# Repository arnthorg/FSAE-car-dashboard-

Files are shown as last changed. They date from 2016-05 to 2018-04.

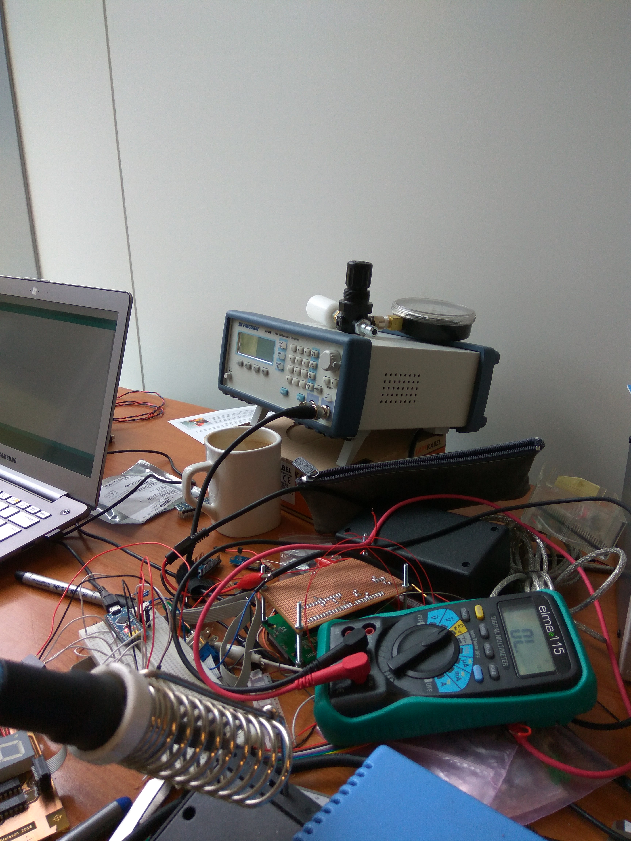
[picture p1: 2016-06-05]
myndir/IMG_20160512_113833.jpg

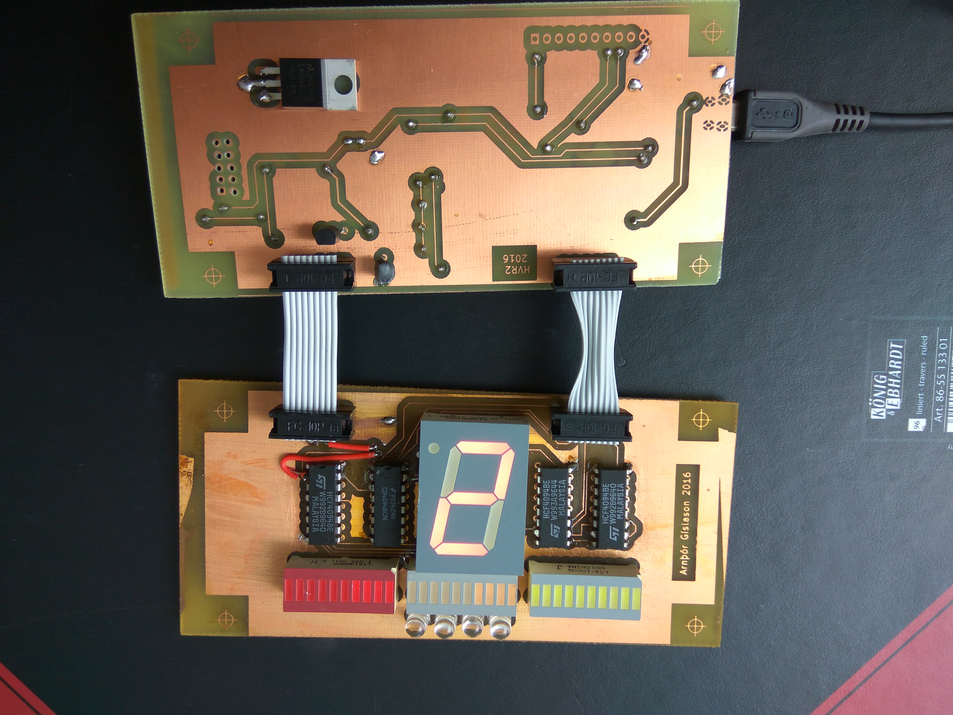
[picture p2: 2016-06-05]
myndir/IMG_20160516_171026.jpg

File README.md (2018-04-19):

# A dashboard with rpm bar-graph, gear display, shift-light and oil pressure/  AFR / Speed for RU's 2016 FSAE car 

It's programmed in the arduino environment 

It has:
* engine RPM bargraph, 
* shift light
* OLED display capable if displaying any analog value
* 7-seg gear selected display

Dash-OLED/ contains the main program

PCB/ contains the PCB design

lid/ contains the sketch for the lid that enclosed the electronics

myndir/ contains some images of the project

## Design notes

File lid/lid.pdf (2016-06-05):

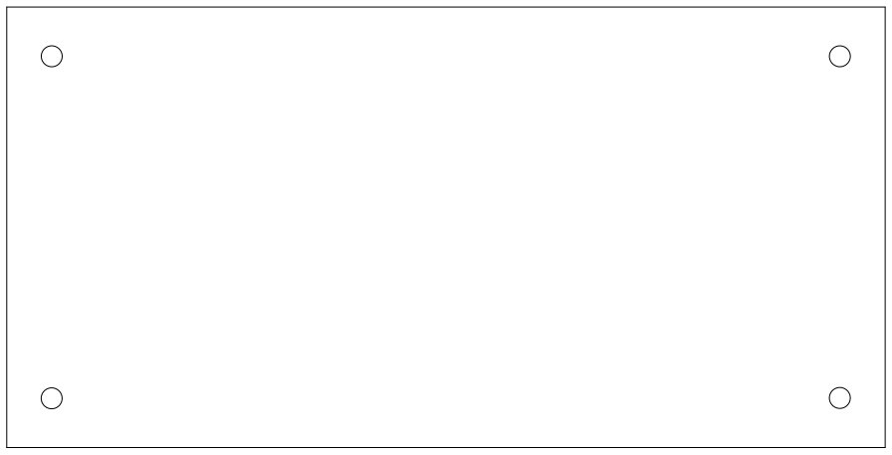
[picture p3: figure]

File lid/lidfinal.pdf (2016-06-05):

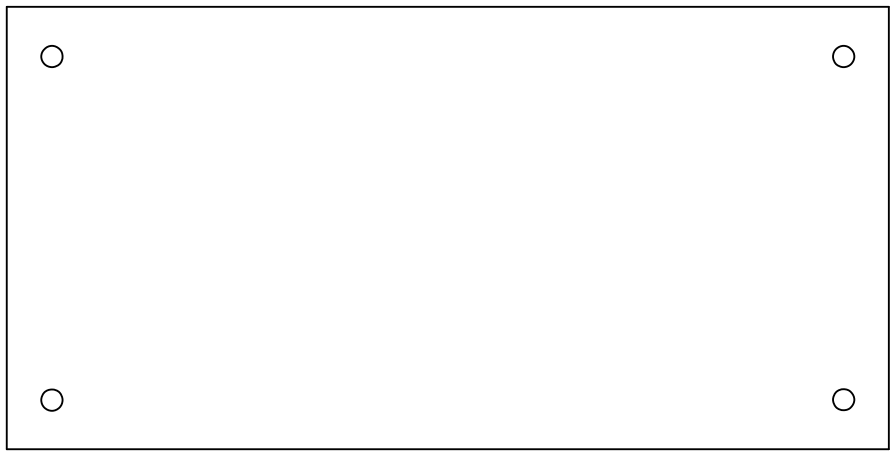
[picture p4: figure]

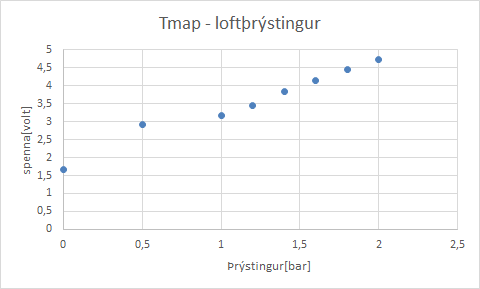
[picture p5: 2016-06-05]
myndir/airpress.png

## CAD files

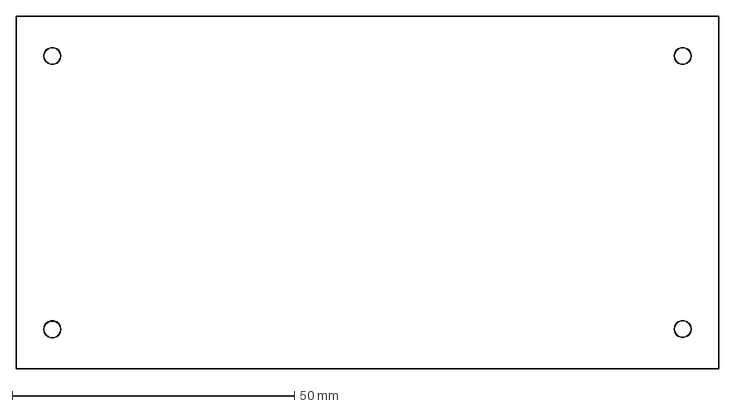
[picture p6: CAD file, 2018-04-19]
lid/lid-F.Fab.dxf
124.5 x 62.4 mm

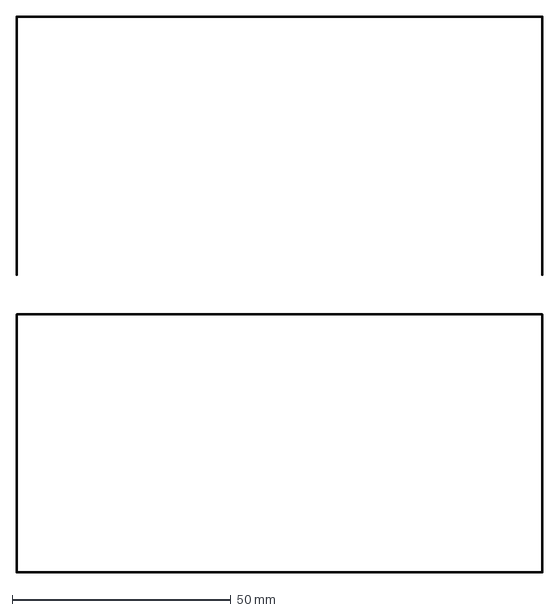
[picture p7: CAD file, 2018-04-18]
PCB/dxf/bargraph-Edge.Cuts.dxf
120.2 x 127.2 mm

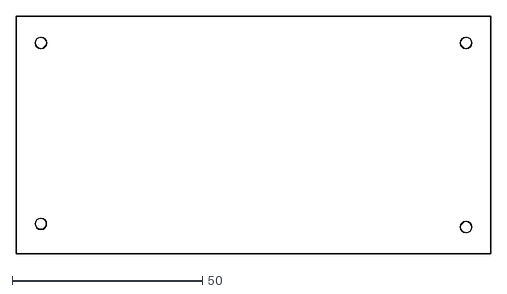
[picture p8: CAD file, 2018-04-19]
lid/Untitled.dxf
124.5 x 62.4

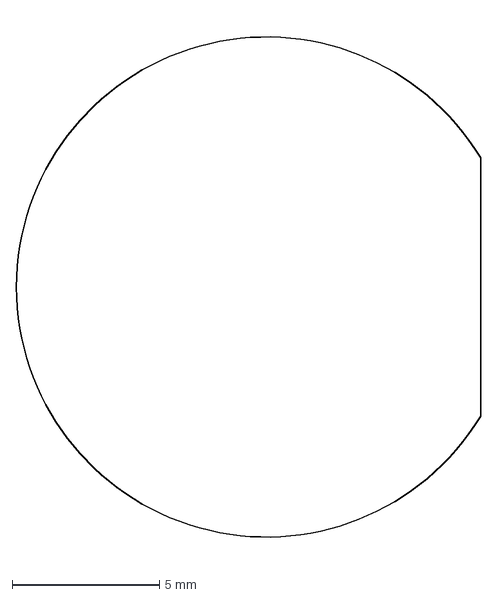
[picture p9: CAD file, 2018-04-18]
lid/conn.dxf
15.8 x 18.4 mm

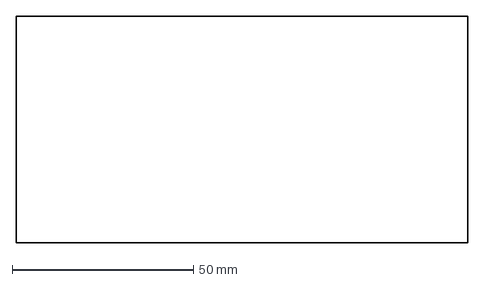
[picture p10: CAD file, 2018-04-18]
lid/#lid.dxf
124.5 x 62.4 mm

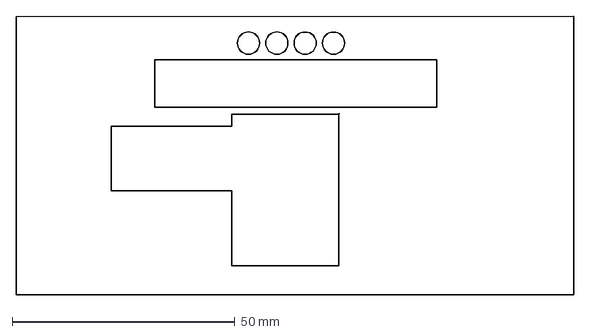
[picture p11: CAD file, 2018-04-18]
lid/spjald.dxf
125.0 x 62.5 mm

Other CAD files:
PCB/dxf/bargraph-F.SilkS.dxf
lid/lid.dxf

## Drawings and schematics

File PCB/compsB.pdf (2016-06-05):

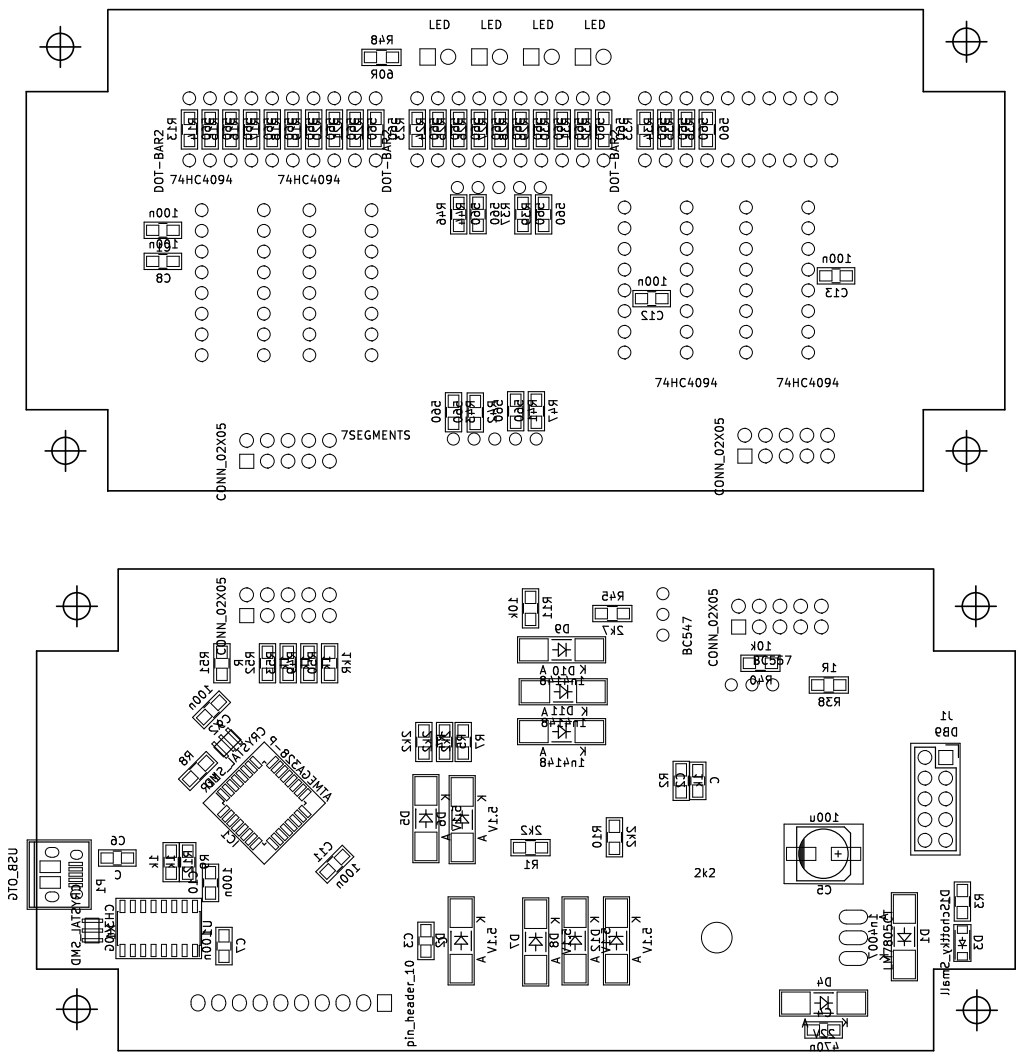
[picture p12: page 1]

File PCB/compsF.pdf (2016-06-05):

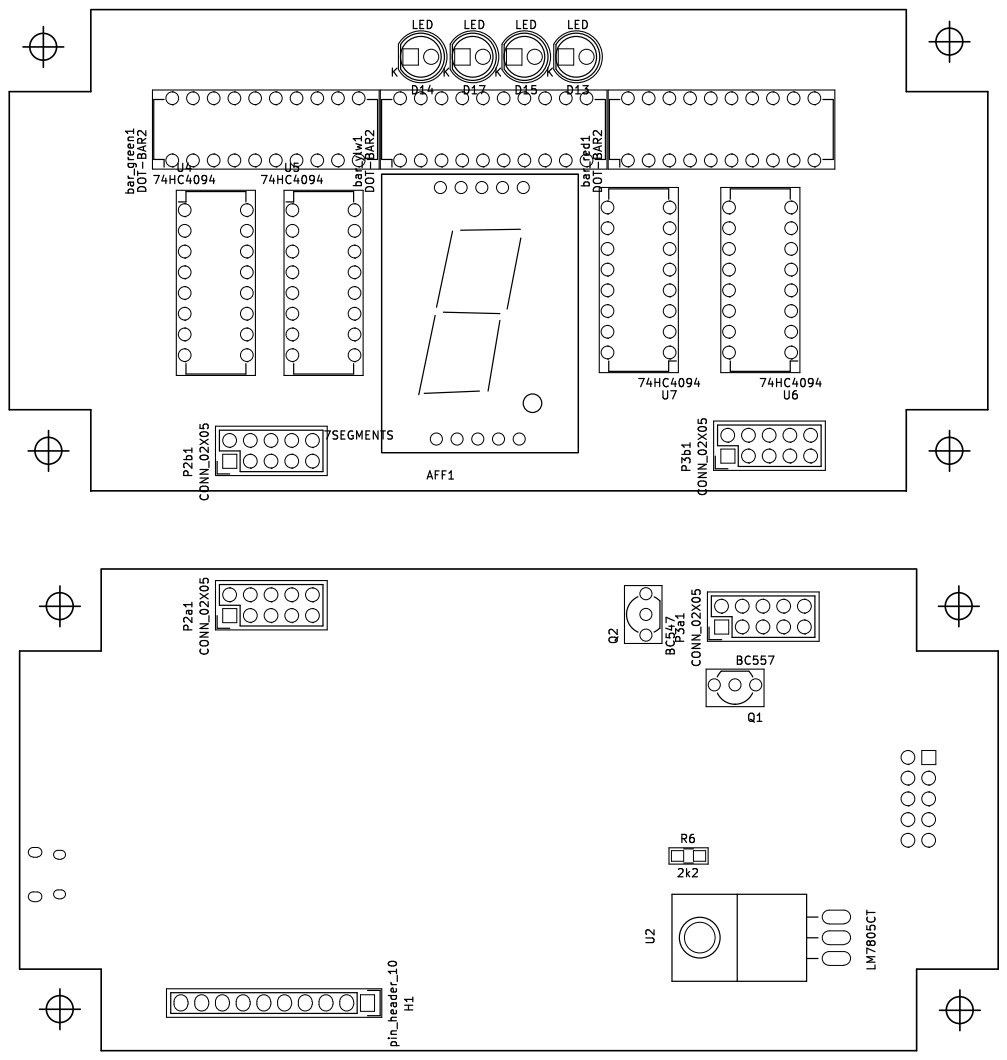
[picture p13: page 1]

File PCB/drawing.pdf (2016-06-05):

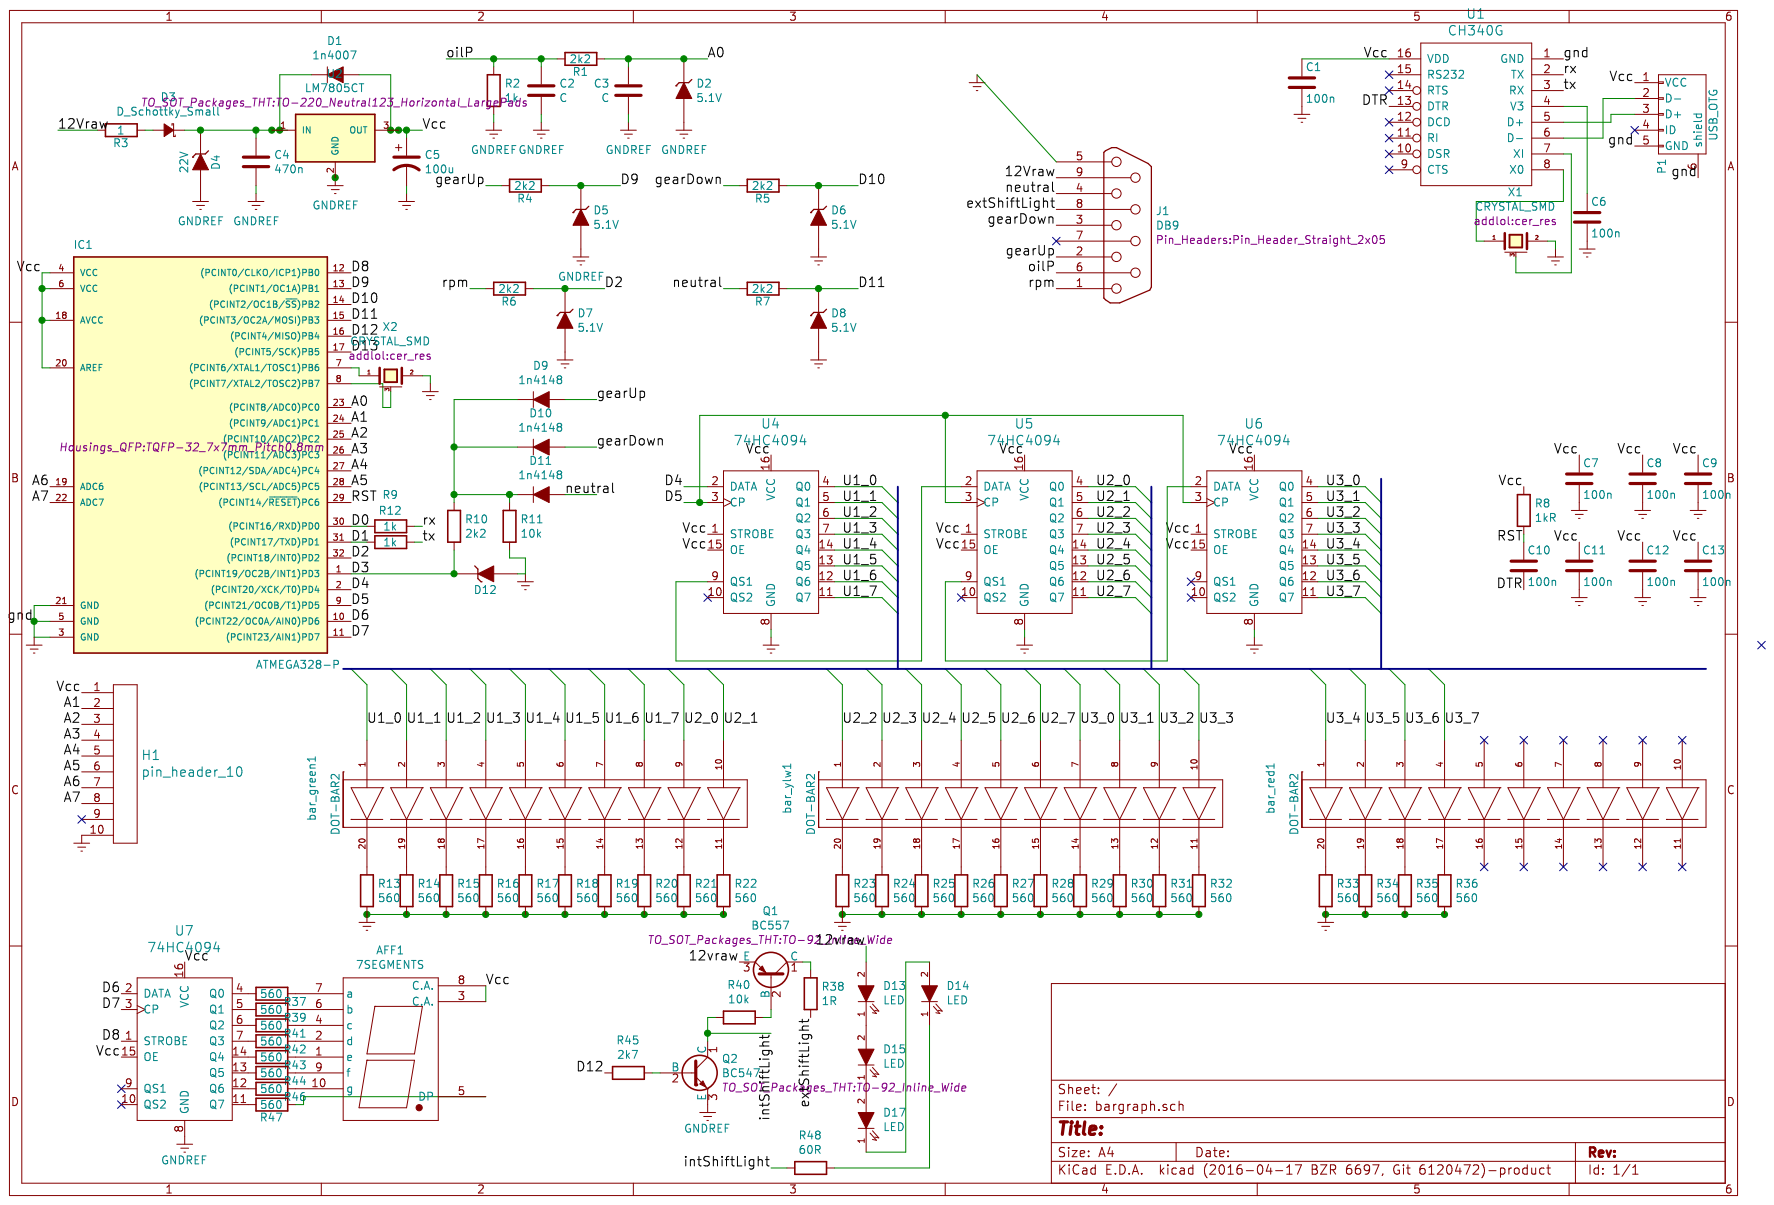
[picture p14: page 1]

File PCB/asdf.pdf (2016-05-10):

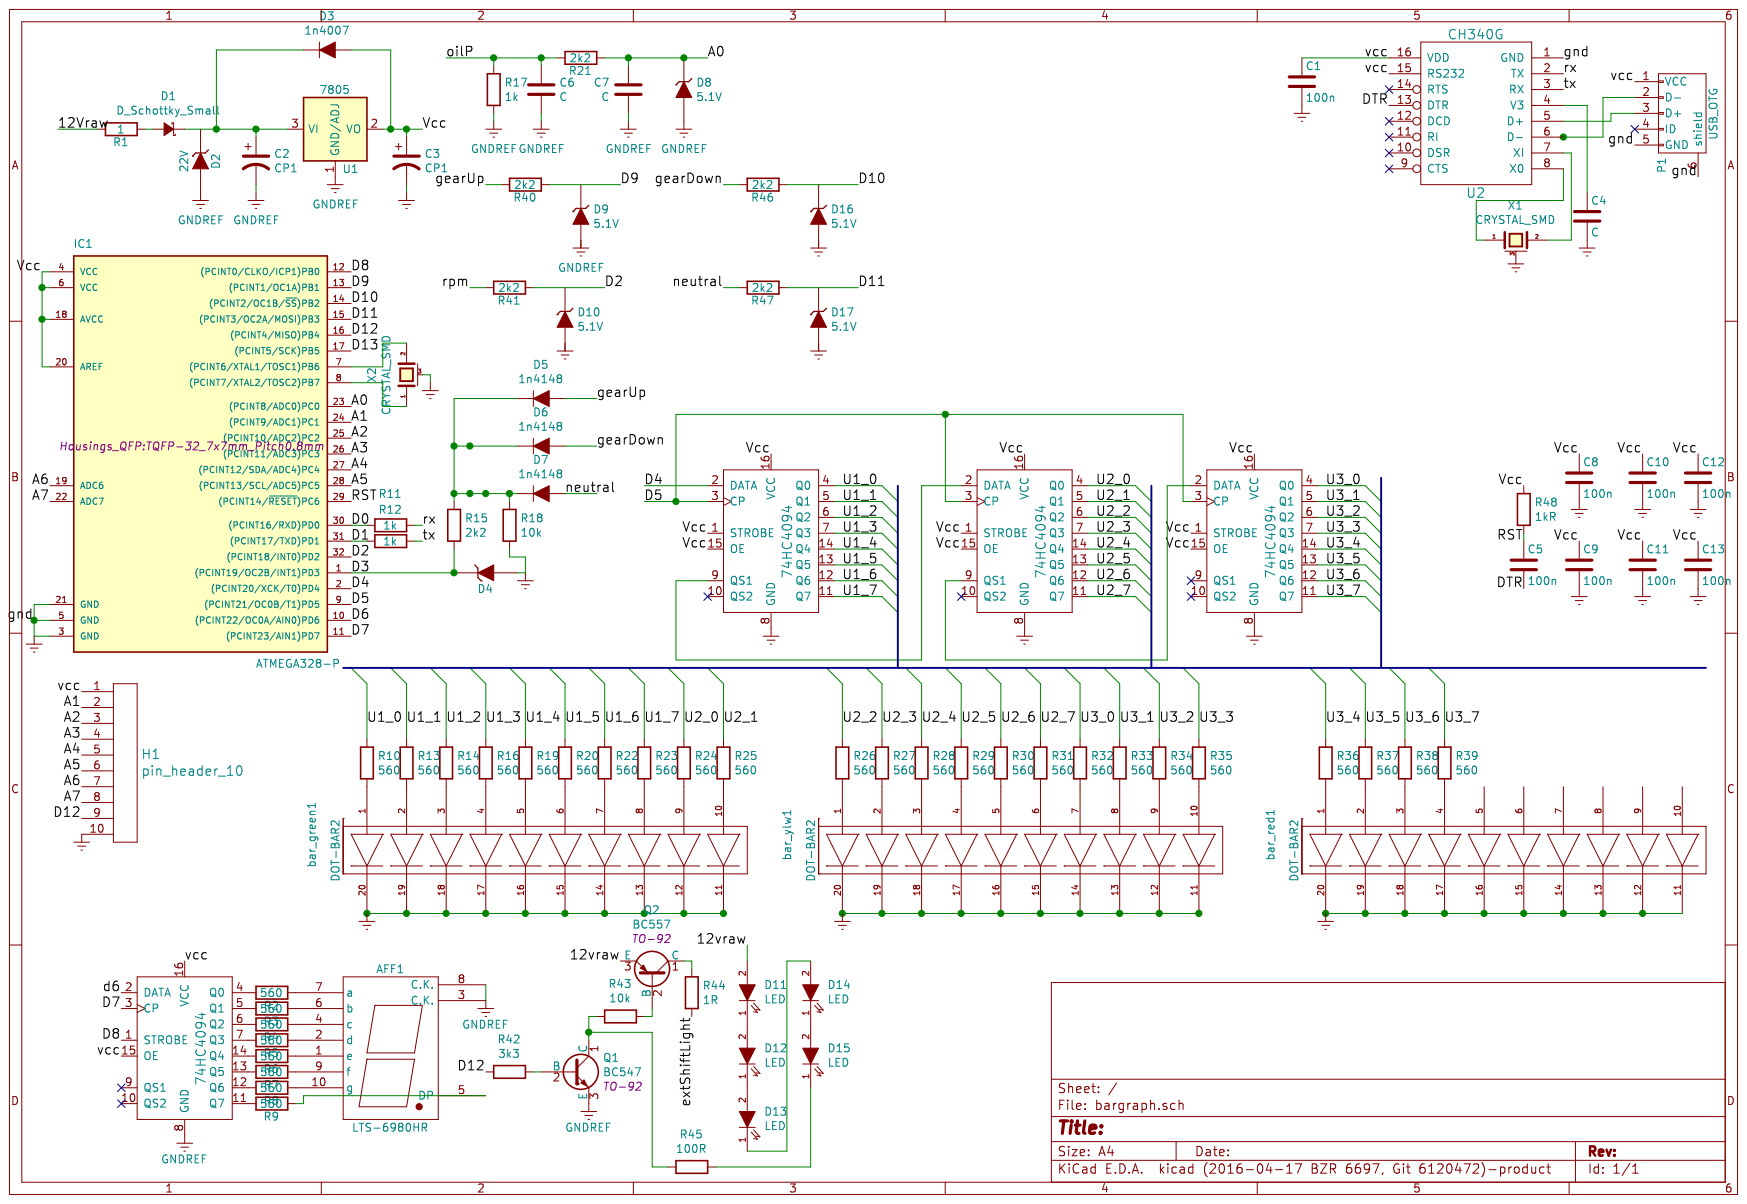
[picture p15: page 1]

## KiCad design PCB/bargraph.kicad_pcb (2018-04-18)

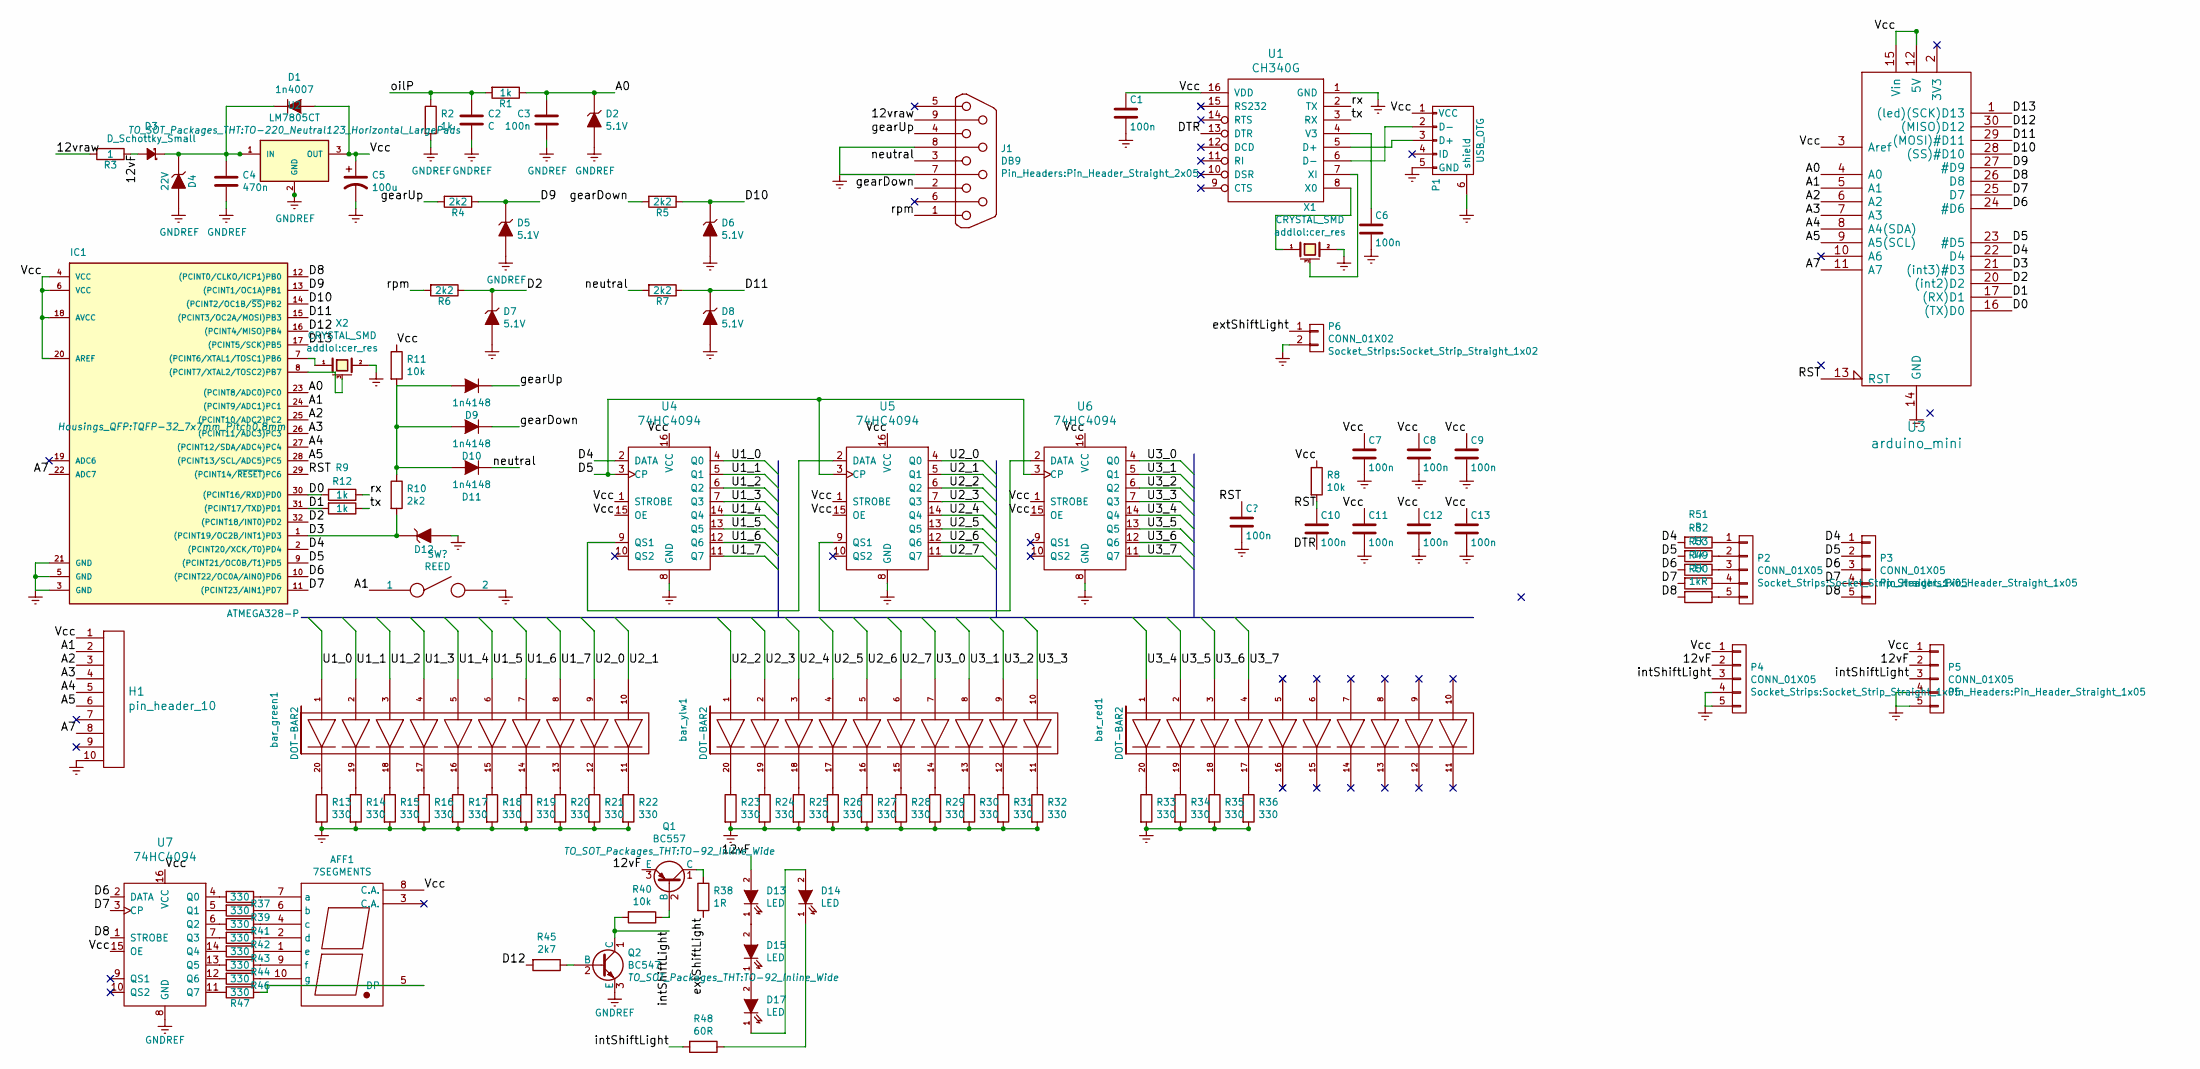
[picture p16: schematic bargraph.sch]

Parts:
AFF1: 7SEGMENTS; 7seg
C1, C3, C6, C7, C8, C9, C10, C11, C12, C13: 100n; C_0805_HandSoldering
C2: C; C_0805_HandSoldering
C4: 470n; C_0805_HandSoldering
C5: 100u; c_elec_6.3x5.8
D1: 1n4007; MELF_Handsoldering
D2, D5, D6, D7, D8, D12: 5.1V; MELF_Handsoldering
D3: D_Schottky_Small; SOD-123
D4: 22V; MELF_Handsoldering
D9, D10, D11: 1n4148; MELF_Handsoldering
D13, D14, D15, D17: LED; LED-5MM
H1: pin_header_10; Pin_Header_Straight_1x10
IC1: ATMEGA328-P; TQFP-32_7x7mm_Pitch0.8mm
J1: DB9; Pin_Header_Straight_2x05
P1: USB_OTG; USB_Micro-B_10103594-0001LF
P2, P4: CONN_01X05; Socket_Strip_Straight_1x05
P3, P5: CONN_01X05; Pin_Header_Straight_1x05
P6: CONN_01X02; Socket_Strip_Straight_1x02
Q1: BC557; TO-92_Inline_Wide
Q2: BC547; TO-92_Inline_Wide
R1, R2, R9, R12, R49, R52, R53: 1k; R_0805_HandSoldering
R3: 1; R_0805_HandSoldering
R4, R5, R6, R7, R10: 2k2; R_0805_HandSoldering
R8, R11, R40: 10k; R_0805_HandSoldering
R13, R14, R15, R16, R17, R18, R19, R20, R21, R22, R23, R24, R25, R26, R27, R28, R29, R30, R31, R32, R33, R34, R35, R36, R37, R39, R41, R42, R43, R44, R46, R47: 330; R_0805_HandSoldering
R38: 1R; R_0805_HandSoldering
R45: 2k7; R_0805_HandSoldering
R48: 60R; R_0805_HandSoldering
R50: 1kR; R_0805_HandSoldering
R51: R; R_0805_HandSoldering
U1: CH340G; SOIC-16_3.9x9.9mm_Pitch1.27mm
U2: LM7805CT; TO-220_Neutral123_Horizontal_LargePads
U3: arduino_mini
U4, U5, U6, U7: 74HC4094; DIP-16_W7.62mm
X1, X2: CRYSTAL_SMD; cer_res
bar_green1: DOT-BAR2; DIP-20_W7.62mm
bar_red1: DOT-BAR2; DIP-20_W7.62mm
bar_ylw1: DOT-BAR2; DIP-20_W7.62mm

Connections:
/12vF: D3.2 (A), D13.2 (A), P4.2, P5.2, Q1.3 (E), R3.1
/12vraw: J1.9, R3.2
/A0: C3.1, D2.1 (K), IC1.23 ((PCINT8/ADC0)PC0), R1.1, U3.4 (A0)
/A1: H1.2, IC1.24 ((PCINT9/ADC1)PC1), U3.5 (A1)
/A2: H1.3, IC1.25 ((PCINT10/ADC2)PC2), U3.6 (A2)
/A3: H1.4, IC1.26 ((PCINT11/ADC3)PC3), U3.7 (A3)
/A4: H1.5, IC1.27 ((PCINT12/SDA/ADC4)PC4), U3.8 (A4(SDA))
/A5: H1.6, IC1.28 ((PCINT13/SCL/ADC5)PC5), U3.9 (A5(SCL))
/A7: H1.8, IC1.22 (ADC7), U3.11 (A7)
/D0: IC1.30 ((PCINT16/RXD)PD0), R9.2, U3.16 ((TX)D0)
/D1: IC1.31 ((PCINT17/TXD)PD1), R12.2, U3.17 ((RX)D1)
/D2: D7.1 (K), IC1.32 ((PCINT18/INT0)PD2), R6.1, U3.20 ((int2)D2)
/D3: D12.1 (K), IC1.1 ((PCINT19/OC2B/INT1)PD3), R10.2, U3.21 ((int3)#D3)
/D4: IC1.2 ((PCINT20/XCK/T0)PD4), P3.1, R51.2, U3.22 (D4), U4.2 (DATA)
/D5: IC1.9 ((PCINT21/OC0B/T1)PD5), P3.2, R52.2, U3.23 (#D5), U4.3 (CP), U5.3 (CP), U6.3 (CP)
/D6: IC1.10 ((PCINT22/OC0A/AIN0)PD6), P3.3, R53.2, U3.24 (#D6), U7.2 (DATA)
/D7: IC1.11 ((PCINT23/AIN1)PD7), P3.4, R49.2, U3.25 (D7), U7.3 (CP)
/D8: IC1.12 ((PCINT0/CLKO/ICP1)PB0), P3.5, R50.2, U3.26 (D8), U7.1 (STROBE)
/D9: D5.1 (K), IC1.13 ((PCINT1/OC1A)PB1), R4.1, U3.27 (#D9)
/D10: D6.1 (K), IC1.14 ((PCINT2/OC1B/~SS~)PB2), R5.1, U3.28 ((SS)#D10)
/D11: D8.1 (K), IC1.15 ((PCINT3/OC2A/MOSI)PB3), R7.1, U3.29 ((MOSI)#D11)
/D12: IC1.16 ((PCINT4/MISO)PB4), R45.2, U3.30 ((MISO)D12)
/D13: IC1.17 ((PCINT5/SCK)PB5), U3.1 ((led)(SCK)D13)
/DTR: C10.2, U1.13 (DTR)
/RST: C10.1, IC1.29 ((PCINT14/~RESET~)PC6), R8.2, U3.13 (RST)
/U1_0: U4.4 (Q0), bar_green1.1 (A)
/U1_1: U4.5 (Q1), bar_green1.2 (A)
/U1_2: U4.6 (Q2), bar_green1.3 (A)
/U1_3: U4.7 (Q3), bar_green1.4 (A)
/U1_4: U4.14 (Q4), bar_green1.5 (A)
/U1_5: U4.13 (Q5), bar_green1.6 (A)
/U1_6: U4.12 (Q6), bar_green1.7 (A)
/U1_7: U4.11 (Q7), bar_green1.8 (A)
/U2_0: U5.4 (Q0), bar_green1.9 (A)
/U2_1: U5.5 (Q1), bar_green1.10 (A)
/U2_2: U5.6 (Q2), bar_ylw1.1 (A)
/U2_3: U5.7 (Q3), bar_ylw1.2 (A)
/U2_4: U5.14 (Q4), bar_ylw1.3 (A)
/U2_5: U5.13 (Q5), bar_ylw1.4 (A)
/U2_6: U5.12 (Q6), bar_ylw1.5 (A)
/U2_7: U5.11 (Q7), bar_ylw1.6 (A)
/U3_0: U6.4 (Q0), bar_ylw1.7 (A)
/U3_1: U6.5 (Q1), bar_ylw1.8 (A)
/U3_2: U6.6 (Q2), bar_ylw1.9 (A)
/U3_3: U6.7 (Q3), bar_ylw1.10 (A)
/U3_4: U6.14 (Q4), bar_red1.1 (A)
/U3_5: U6.13 (Q5), bar_red1.2 (A)
/U3_6: U6.12 (Q6), bar_red1.3 (A)
/U3_7: U6.11 (Q7), bar_red1.4 (A)
/extShiftLight: P6.1, R38.2
/intShiftLight: P4.3, P5.3, Q2.1 (C), R40.2, R48.2
/oilP: C2.1, R1.2, R2.1
/rpm: J1.1, R6.2
/rx: R9.1, U1.2 (TX)
/tx: R12.1, U1.3 (RX)
unnamed: AFF1.1 (e), R43.1
unnamed: AFF1.2 (d), R42.1
unnamed: AFF1.4 (c), R41.1
unnamed: AFF1.5 (DP), R47.1
unnamed: AFF1.6 (b), R39.1
unnamed: AFF1.7 (a), R37.1
unnamed: AFF1.9 (f), R44.1
unnamed: AFF1.10 (g), R46.1
unnamed: C4.1, D1.1 (K), D3.1 (K), D4.1 (K), U2.1 (IN)
unnamed: C6.1, U1.4 (V3)
unnamed: D13.1 (K), D15.2 (A)
unnamed: D14.1 (K), R48.1
unnamed: D14.2 (A), D17.1 (K)
unnamed: D15.1 (K), D17.2 (A)
unnamed: IC1.7 ((PCINT6/XTAL1/TOSC1)PB6), X2.1
unnamed: IC1.8 ((PCINT7/XTAL2/TOSC2)PB7), X2.3 (case)
unnamed: P1.2 (D-), U1.6 (D-)
unnamed: P1.3 (D+), U1.5 (D+)
unnamed: P2.1, R51.1
unnamed: P2.2, R52.1
unnamed: P2.3, R53.1
unnamed: P2.4, R49.1
unnamed: P2.5, R50.1
unnamed: Q1.1 (C), R38.1
unnamed: Q1.2 (B), R40.1
unnamed: Q2.2 (B), R45.1
unnamed: R13.1, bar_green1.20 (K)
unnamed: R14.1, bar_green1.19 (K)
unnamed: R15.1, bar_green1.18 (K)
unnamed: R16.1, bar_green1.17 (K)
unnamed: R17.1, bar_green1.16 (K)
unnamed: R18.1, bar_green1.15 (K)
unnamed: R19.1, bar_green1.14 (K)
unnamed: R20.1, bar_green1.13 (K)
unnamed: R21.1, bar_green1.12 (K)
unnamed: R22.1, bar_green1.11 (K)
unnamed: R23.1, bar_ylw1.20 (K)
unnamed: R24.1, bar_ylw1.19 (K)
unnamed: R25.1, bar_ylw1.18 (K)
unnamed: R26.1, bar_ylw1.17 (K)
unnamed: R27.1, bar_ylw1.16 (K)
unnamed: R28.1, bar_ylw1.15 (K)
unnamed: R29.1, bar_ylw1.14 (K)
unnamed: R30.1, bar_ylw1.13 (K)
unnamed: R31.1, bar_ylw1.12 (K)
unnamed: R32.1, bar_ylw1.11 (K)
unnamed: R33.1, bar_red1.20 (K)
unnamed: R34.1, bar_red1.19 (K)
unnamed: R35.1, bar_red1.18 (K)
unnamed: R36.1, bar_red1.17 (K)
unnamed: R37.2, U7.4 (Q0)
unnamed: R39.2, U7.5 (Q1)
unnamed: R41.2, U7.6 (Q2)
unnamed: R42.2, U7.7 (Q3)
unnamed: R43.2, U7.14 (Q4)
unnamed: R44.2, U7.13 (Q5)
unnamed: R46.2, U7.12 (Q6)
unnamed: R47.2, U7.11 (Q7)
unnamed: U1.7 (XI), X1.3 (case)
unnamed: U1.8 (X0), X1.1
unnamed: U4.9 (QS1), U5.2 (DATA)
unnamed: U5.9 (QS1), U6.2 (DATA)

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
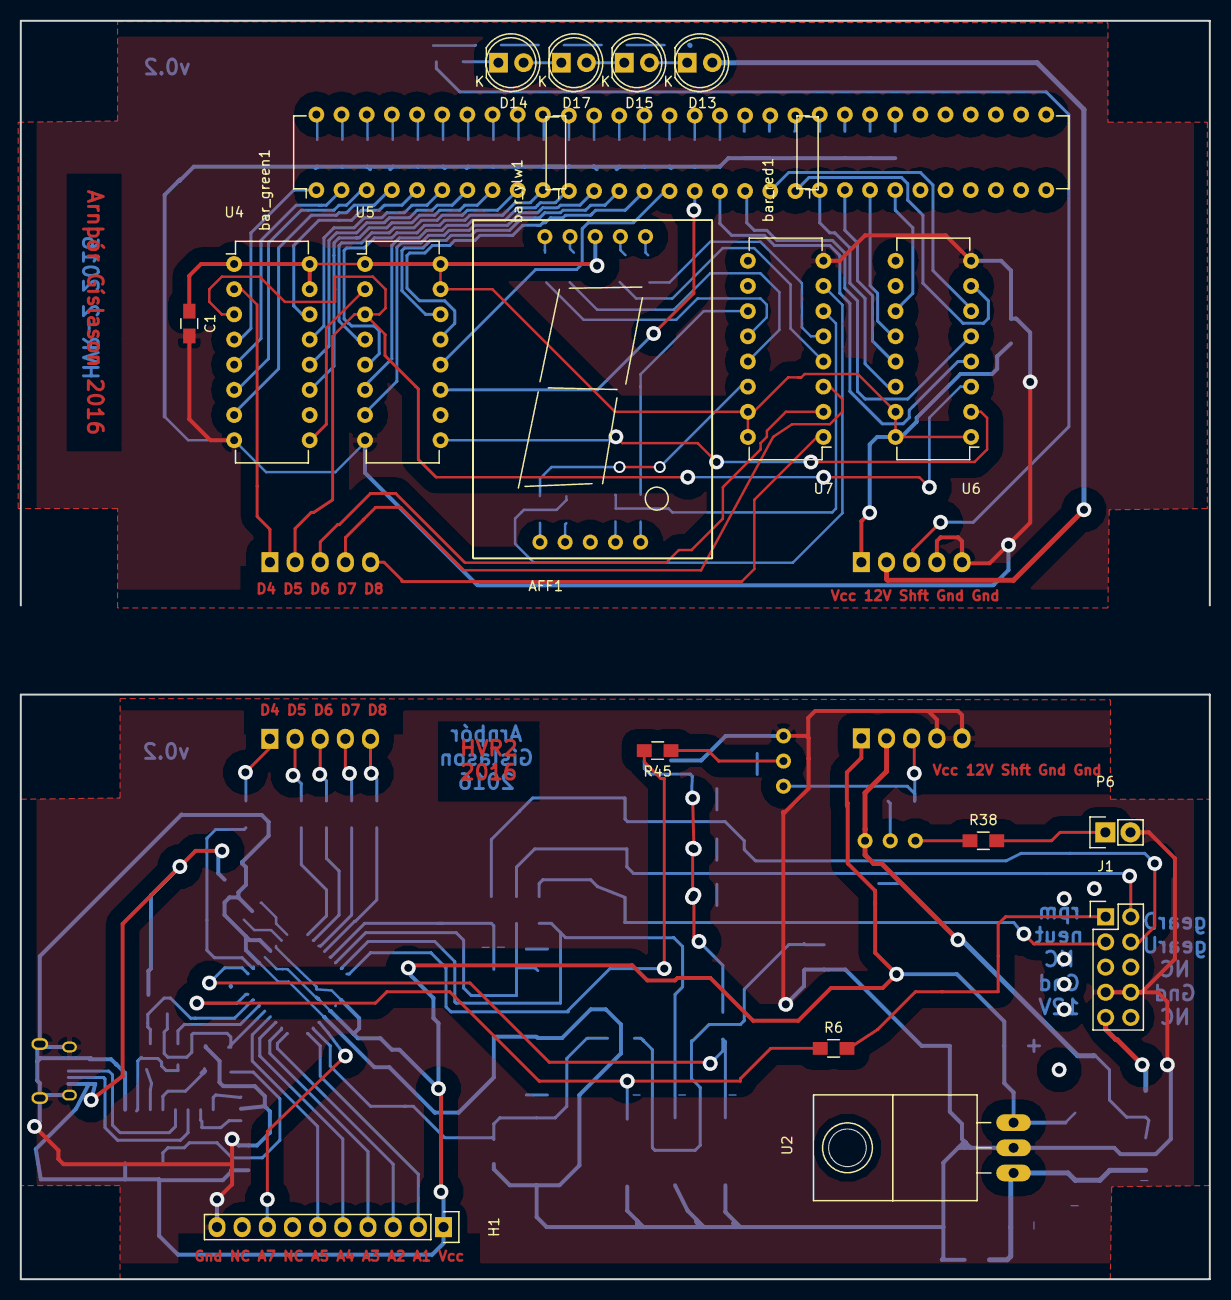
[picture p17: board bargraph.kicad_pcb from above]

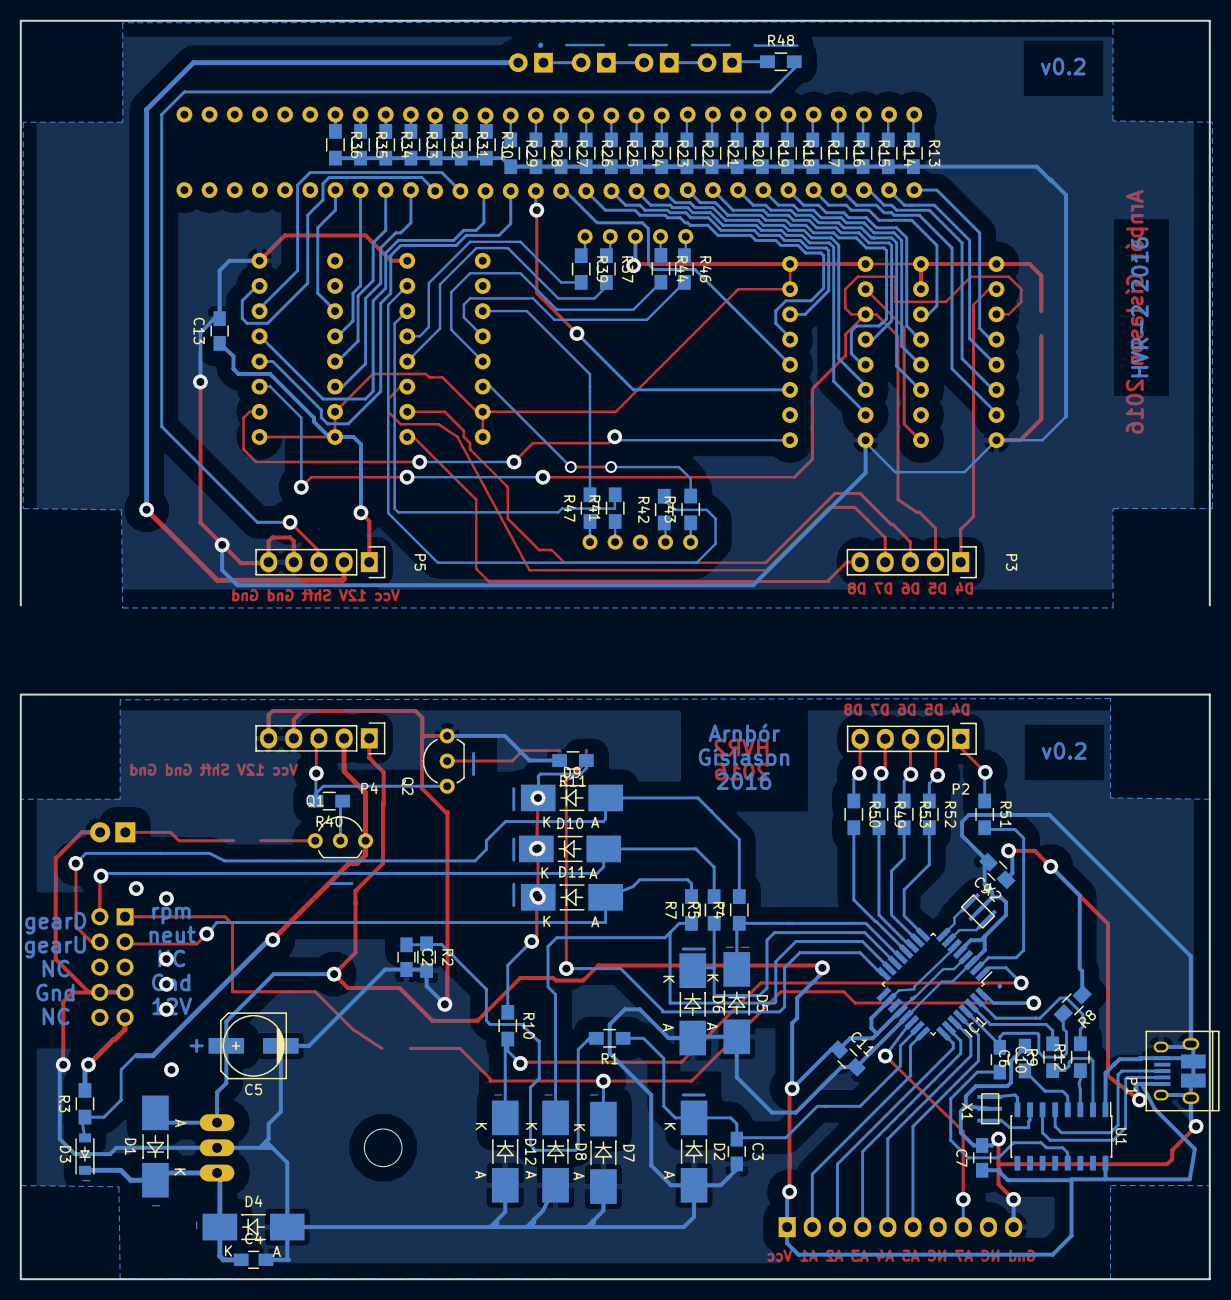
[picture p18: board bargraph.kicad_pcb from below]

Board: 2 copper layers, 120.0 x 127.0 mm, 103 parts (83 on the bottom side), 122 nets.

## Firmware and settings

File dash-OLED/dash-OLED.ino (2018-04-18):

#include "stdbool.h"
#include <avr/wdt.h> // watchdog
#include <EEPROM.h>
#include <SPI.h>
#include <Wire.h>
#include <Adafruit_GFX.h>
#include <Adafruit_SSD1306.h>
#include <PinChangeInterruptBoards.h>
#include <YetAnotherPcInt.h>

#define interruptPin2 2
#define interruptPin3 3
#define Data 4 // D4
#define CP 5 //   D5
#define Data7 6 //D6
#define CP7 7
#define Latch7 8 //PORTB tekur við
#define gearUp 9
#define gearDown 10
#define neutral 11
#define shiftLight 12
#define oilP A0
//fyrir skjá
#define OLED_RESET A3
Adafruit_SSD1306 display(OLED_RESET);


const unsigned short SHIFT_RPM = 8500;
const unsigned short MAX_RPM = 9100;
const char BAR_SIZE = 24;
const byte digit[8] = { B00001010, B01100000, B00101010,         //r,1,n,2,3,4,5,E
                        B11011010, B11110010, B01100110,
                        B10110110, B10011110
                      };
const float FINAL_DRIVE = 32.0/14.0 * 2.88;
const float GEAR_RATIO[8] = {10000, 2.36, 10000, 1.87, 1.53, 1.24, 0.96, 10000 }; //deila með stórri tölu til að fá 0 þegar n eða E er valið
const float PI_OVER_30_TIMES_R = 50*3.14/60/1000;

volatile unsigned long g_lastInterrupt;
volatile unsigned long g_lastInterrupt2;
volatile unsigned char g_pos = 0;
volatile unsigned long g_menuLastInterrupt;
volatile unsigned short g_rpm[10] = { 0 };
volatile unsigned char g_menu = 0;
volatile bool g_barGraphArr[BAR_SIZE] = { 0 };
volatile bool g_periodOn7SegDisp = 0;
volatile char g_selectedGear = 7;
volatile bool g_menuChanged = true;

void setup() {
  display.begin(SSD1306_SWITCHCAPVCC, 0x3C);
  display.display();
  //Serial.begin(9600);
  pinMode(interruptPin2, INPUT);
  pinMode(interruptPin3, INPUT); 
  pinMode(neutral, INPUT_PULLUP); 
  pinMode(Data, OUTPUT);
  pinMode(CP, OUTPUT);
  pinMode(CP7, OUTPUT);
  pinMode(Data7, OUTPUT);
  pinMode(Latch7, OUTPUT);
  pinMode(shiftLight, OUTPUT);
  pinMode(gearUp, INPUT_PULLUP);
  pinMode(gearDown, INPUT_PULLUP);
  pinMode(A0, INPUT); // AFR
  pinMode(A1, INPUT_PULLUP); // mode rofi
  analogReference(DEFAULT);
  PORTD = 0;
  PORTB = 0;
  delay(100); //maybe this delay is important?
  attachInterrupt(digitalPinToInterrupt(interruptPin2), blink, RISING);
  attachInterrupt(digitalPinToInterrupt(interruptPin3), setGear, FALLING);
  PcInt::attachInterrupt(A1, nextMenu, "", FALLING);   //set interrupt A1;
  PcInt::attachInterrupt(gearUp, gearUpRising, "", CHANGE);
  PcInt::attachInterrupt(gearDown, gearDownRising, "", CHANGE);
  //if ((PINB & (1 << neutral - 8))) sevenSeg(7); //display E on 7seg if n is high
  if( (PINB & (1<<gearUp - 8)) && (PINB & (1<<gearDown - 8))) sevenSeg(7); //display E on 7seg if gearUp && gearDown are high
  else {
    g_selectedGear = 2; // 2 being neutral
    sevenSeg(1);
  }
  //fyrir skjá
}

void loop() {
  //delay(250);
  short rpm = calcRpmAvg();
  barGraph(rpm);
  displayUpdate(rpm);
  sevenSeg(g_selectedGear);
  /*bool gearUpState = (PINB & (1 << (gearUp - 8)));
  bool gearDownState = (PINB & (1 << (gearDown - 8)));
  if( !gearUpState && !gearDownState) {
      g_selectedGear = 2;           //2 being neutral
  } */ 
  delay(10);
}
void gearUpRising(const char* message, bool pinstate) {
  bool gearUpState = (PINB & (1 << (gearUp - 8)));
  bool gearDownState = (PINB & (1 << (gearDown - 8)));
  if(gearUpState && !gearDownState && g_selectedGear == 2) { //þá er neutral rofinn líklega að detta út og það er verið að skipta úr n í 1
    g_selectedGear--;
  }
  unsigned long g_lastInterrupt2 = micros(); // til að það skiptist ekki um gír þegar rofinn opnar síðan
}
void gearDownRising(const char* message, bool pinstate) {
  bool gearUpState = (PINB & (1 << (gearUp - 8)));
  bool gearDownState = (PINB & (1 << (gearDown - 8)));
  if(!gearUpState && gearDownState && g_selectedGear == 2) {
    g_selectedGear++;
  }
  unsigned long g_lastInterrupt2 = micros()- 100000; // til að það skiptist ekki um gír þegar rofinn opnar síðan, bæti við 100ms
}
void nextMenu(const char* message, bool pinstate) {
  unsigned long currentInterrupt = micros();
  if ((currentInterrupt - g_menuLastInterrupt) > 5e4) { //debounce 5.0ms
    g_menu++;
    if(g_menu > 1) 
      g_menu = 0;
  }
  g_menuLastInterrupt = currentInterrupt;
  g_menuChanged = true;
}
void displayUpdate(short rpm) {
    if(g_menuChanged) {
      display.clearDisplay();
  }
  switch(g_menu) {
    case 0: { //hraði
      displayPrintThreeNums(rpm * PI_OVER_30_TIMES_R / (FINAL_DRIVE * GEAR_RATIO[g_selectedGear]), 0, 0);
    }
    break;
    case 1: {
       float volts = analogRead(A0)*5.0/102.4;
       displayPrintThreeNums(volts*2.006+49, 0, true);
    }
    break;
    
  }
  if(g_menuChanged) {
      displayPrintVertical(g_menu);
      if(g_menu == 1) {
        display.setCursor(63,45);
        display.write(0x2C);
      }
      g_menuChanged = false;
  }
  display.display();
}
void displayPrintVertical(char choice) {
  switch (choice) {
    case 0: {
      display.setTextSize(3);
      display.setCursor(108,0);
      display.print("K");
      display.setCursor(108,18);
      display.print("m");
      display.setCursor(108,42);
      display.print("h");
      //display.display();
    }
    break;
    case 1: {
      display.setTextSize(2);
      display.setCursor(108,7);
      display.print("A");
      display.setCursor(108,23);
      display.print("F");
      display.setCursor(108,39);
      display.print("R");
      //display.display();
    }
    break;
  }
}
void displayPrintThreeNums(float input, short decimals, bool period) {
  display.setTextSize(6);
  display.setTextColor(BLACK);
  display.setCursor(0,10);
  for(int i = 0; i<3;i++) {
    display.write(0xDA);
  }
  display.setCursor(0,10);
  if(int(input)/10 ==0) display.print(" ");
  if(int(input)/100 ==0) display.print(" ");
  
  display.setTextColor(WHITE);
  display.print(input, decimals);
  //display.display();
}


void setGear() { 
  bool gearUpState = (PINB & (1 << (gearUp - 8)));
  bool gearDownState = (PINB & (1 << (gearDown - 8)));
  unsigned long currentInterrupt = micros();
  if ((currentInterrupt - g_lastInterrupt2) > 20e4) { //debounce 7ms = 7000µs
    //if (!(PINB & (1 << (neutral - 8)))) {          // ef neutral er low
    if( !gearUpState && !gearDownState) {
      g_selectedGear = 2;           //2 being neutral
      return;
    }
    if (!gearUpState && g_selectedGear < 6) {
      g_selectedGear++;
    }
    else if (!gearDownState && g_selectedGear > 1 && g_selectedGear < 7) {
      g_selectedGear--;
    }
    sevenSeg(g_selectedGear);
    g_lastInterrupt2 = currentInterrupt;
  }
}

void barGraph(int rpm) {
  num2array(rpm);
  for (int iter = 0; iter < BAR_SIZE; iter++) {
    bool x = g_barGraphArr[BAR_SIZE - iter - 1];
    PORTD ^= (-x ^ PORTD) & (1 << Data);
    PORTD |= (1 << CP);
    PORTD &= ~(1 << CP);
  }
}

unsigned int calcRpmAvg() {
  float sum = 0;
  for (int iter = 0; iter < 10; iter++) {
    sum += g_rpm[iter];
  }
  return sum / 10;
}

void blink() { // int0
  unsigned long currentInterrupt = micros();
  if ((currentInterrupt - g_lastInterrupt) > 5 * 1000) { //debounce
    calculateRpm(currentInterrupt);
    g_lastInterrupt = currentInterrupt;
  }
  if(g_rpm[g_pos] >= SHIFT_RPM) {
    PORTB |= (1<<shiftLight-8);
  }
  else 
    PORTB &= ~(1<<shiftLight-8);
}

void calculateRpm(unsigned long currentInterrupt) { //calculates RPM from deltaT
  float deltaT;
  deltaT = currentInterrupt - g_lastInterrupt;
  deltaT = 1e6 / deltaT;
  deltaT *= 60;
  g_rpm[g_pos] = deltaT;
  g_pos++;
  if (g_pos > 9) g_pos = 0;
}

void num2array(short rpm) { // converts rpm to an array of bits to bang into shift registers
  int range = MAX_RPM / BAR_SIZE;
  for (int iter = 0; iter < BAR_SIZE; iter++) {
    if (rpm > range * iter) {
      g_barGraphArr[iter] = 1;
    }
    else g_barGraphArr[iter] = 0;
  }
}
void sevenSeg(short symbol) {
  byte digitTmp = 0;
  if (symbol > 6)
    digitTmp = digit[7]; //if symbol is greater than 6 display E
  else {
    digitTmp = digit[symbol];
  }
  digitTmp ^= (-g_periodOn7SegDisp ^ digitTmp) & 1;

  shiftOut(Data7, CP7, LSBFIRST, ~digitTmp);
  PORTB |= 1; //(1<<Latch7-8);
  delayMicroseconds(10); //datasheet segir 200ns min en þarf alveg 10µs t_w
  PORTB &= ~1; //(1<<Latch7-8);
}

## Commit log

2016-04-28 Creating a new repo
    [hitanemar.xlsx]
2016-04-30 Adding measurements
    [olíuþrýstingur_viðnámsmælingar.xlsx]
2016-05-01 some changes + new data for TMAP NTC
    [olíuþrýstingur_viðnámsmælingar.xlsx]
2016-05-04 rpm mælingar m. interrupt og fleira data
    [olíuþrýstingur_viðnámsmælingar.xlsx]
2016-05-06 Began drawing a schematic for the circuit
    [_saved_bargraph.sch, bargraph.kicad_pcb, bargraph.sch]
2016-05-07 completed gearcounter
2016-05-07 new file, gearcounter completed
2016-05-09 Progress on the schematic
    [_saved_bargraph.sch, bargraph.sch]
2016-05-09 moving between folders
    [bargraph.kicad_pcb, bargraph.sch]
2016-05-10 Can't be bothered with the watchdog timer
2016-05-11 One of the boards completed at least
    [_saved_bargraph.sch, bargraph.kicad_pcb, bargraph.sch]
2016-05-16 Fixing bugs in the PCB designe
    [_saved_bargraph.sch, bargraph.kicad_pcb, bargraph.sch]
2016-06-05 adding stuff
    [#lid.dxf, TPS skynjari.xlsx, Untitled.dxf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]
2016-06-05 changing gearup geardown and netural to be active low
2018-04-18 committing very old unsaved changes
    [#lid.dxf, bargraph-Edge.Cuts.dxf, bargraph-F.SilkS.dxf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]
2018-04-19 moving things around and removing irrelevant stuff
    [#lid.dxf, Untitled.dxf, bargraph-Edge.Cuts.dxf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]
2018-04-19 removing irrelevant stuff
    [TPS skynjari.xlsx, hitanemar.xlsx]
